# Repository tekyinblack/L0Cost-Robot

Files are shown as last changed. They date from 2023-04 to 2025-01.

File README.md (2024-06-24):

# L0Cost-Robot
This repository holds code for the L0Cost robot project which aims to create designs for robots which don't exceed $20. Inevitably this limit will get broken, but the limit will only increase with general inflation, not wild spending budgets!
The current target platform is the ESP32-CAM board as it provides a good mix of faclities without needing modification. The aim is not to make this platform totally autonomous, but to place control elsewhere such that, say, it might be controlled from a program on a PC or tablet, and as such be controlled in conjunction with other robots. Some basic video recognition code is included to facilitate basic line following and blob location using the camera.

It is also fully expected that the basic platform wil be augmented with a co-processor to handle more extensive I/O operations

The ESP32-CAM is a powerful microcontroller, with a fitted camera, Wi-Fi, Bluetooth and an SD card reader and while worldwide prices will vary, it does represent very good value for money. 
This module can be used just as a remote video camera with SD card configuration, upgraded to have a pan and tilt mount, then added to a small robot, examples of which will be loaded later. 
One target audience is educators who want an easily configurable and repeatable platform at a low cost to aid in STEM robot deployment.

Example configurations are
Pan & Tilt platform controller from web page
Basic RC robot using TT motors controlled from webpage with video feed
Extended robot with control from PS3, web page or self guided

Further configurations extend the capabilities with a Raspberry Pi Pico 

The file SDcard files.docx details the files on the SD card which are used to configure the robot without having to reload the code to the controller
The file  Command Processing.docx details the current state of the command set used to automate the robot controller.

A structure has not yet been designed to support command input instigation of self guidance features so these may appear in the code as switches but are not yet finalised.

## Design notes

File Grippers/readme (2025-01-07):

These are demonstration programs for grippers using SG90 or MG90 servos
They are to setup the servo to 90 degrees to aid assembly, move the servo between 70 and 120
degrees to test operation, and a program to grip objects, either with feedback from the servo
or from metal contacts in the arms detecting the conductivity of the object being gripped.

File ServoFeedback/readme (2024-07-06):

These are the test and demonstration programs for SG90 or MG90 servos modified to use the feedback signal from the servo
They are:
1. Test the servo panning from 0-180-0 degrees and reading the feedback output. The output is formatted for input to the Arduino serial plotting screen. This also verifies that the servo is working after the modification.
2. Initialise the servo to its current position on start up. Switch off, move the servo arm and switch on so that the operation can be confirmed. Compare this to the way the servo behaves on start up with program 1.
3. Stop the servo being overloaded. With this program running and the servo arm fitted hold the servo arm tight when it tries to turn, the servo should initially attempt to turn but then stop with an error message on the serial console
4. Report the current servo position. The servo will move and a report will be sent to to the serial console where the arm is and when it reaches its destination.

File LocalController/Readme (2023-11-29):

There are two versions of the local controller designed, one using the Arduino Nano format and the other the Raspberry Pi Pico format.
Designs and code for each are held separately in their respective folders

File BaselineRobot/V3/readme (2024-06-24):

This is the code base for the version 3 ESP32 sdk

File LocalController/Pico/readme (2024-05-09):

This is the design and code for the local controller based on a Raspberry Pi Pico associated with the L0Cost robot
The design arose out of a PiWars 2024 entry

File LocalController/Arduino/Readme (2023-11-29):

This folder contains designs and code for the Arduino Nano version of the Local Controller held in their respective folders, as well a pictures of completed boards.

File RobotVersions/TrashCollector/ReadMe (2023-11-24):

Trash Collector
This small robot is equiped with a grab and hopper to collect small pieces of trash and deliver them 
to a dump, using the images viewed through the robots camera.

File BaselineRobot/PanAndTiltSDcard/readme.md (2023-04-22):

This is a typical set of files to run a simple Pan and Tilt system
with two servos and an ESP32-CAM module. 
Customise the files as required to setup the operation and
provide a degree of remote control and automation.
Further details will be on instructables.com tagged as L0cost robot.

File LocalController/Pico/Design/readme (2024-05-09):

Information associated with teh Pico version of the local controller will appear here

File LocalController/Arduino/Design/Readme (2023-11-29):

This folder contains design material for the Arduino version of the Local Controller

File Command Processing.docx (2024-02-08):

# L0Cost Robot Commands

The following tables list the commands the L0Cost robot controller accepts and describes what each command does. This is not a sophisticated command structure and is intended to provide a very simple to implement interface and script facility in order to enable rapid learning and play. The source code is available and while any part of it can be modified, additional commands can be added through blank template functions.

Read this together with the example scripts and web pages to understand what is being done.

Command Source Code | Explanation
0 | An internal command, executed with high priority
1 | A command received from a web browser. An ACK or NACK message is pushed back if the web page can handle it.
2 | A command received as part of a script file. If the command fails, a test flag is set and unset on execution of the next successful command. Until a script command is complete, no further script commands are processed.
3 | A command received from PS3 controller processing. No error indicators are returned
4 | A command received from the serial port. This runs at 115200 baud, and an ACK or NACK message is returned depending on command success. A command may be an ACK, or a NACK from a command sent to a remote machine.

Command Prefix | Explanation
L | This command is for execution on the local machine. The command text is trimmed and forwarded to the local command processor. If the command is not recognised as a local command then an execution failure is returned.
LC | Commands for the local camera operation
LG | Commands for the local video guidance operation
F | This command identifies a script file which is opened and read, the contents being executed. Some commands can only be executed from within script files. If the file fails to open then an execution failure is returned. Script files can contain both local and remote commands but not file commands, script nesting is not yet supported but planned.
X | This command is for execution on a remote machine attached to the serial port. The command text is trimmed and forwarded to the serial port. The serial port is configured to run at 115200 baud.
H | This command passes the string following to the webserver unaltered to be retrieved by a javascript, or other, in the browser. The default string returned is {“type”:null}. For example H{“type”:”user”,”speed”:”20”,”distance”:”9”} might indicate to the browser script that this is user data, the speed value is 20cm/s and the distance is 9cm.
P | This command sends instructions to the PS3 controller, limited to lights status and vibration.
T | This command sets execution flags. TON sets execution flag positive or true, TOFF set the execution flag negative or false, TNULL sets the execution flag to neither.

Guidance Local Commands | Guidance Commands Explanation Guidance commands are ignored when guidance isn’t enabled
VIDEO | Sends frames for streaming when guidance active. This may significantly reduce the frame rate
GUIDE | Activates guidance mode. May change the aspect ratio of any streamed video or interrupt it
GREEN | Sets the individual detection threshold for green pixels on all detection methods. A positive value indicates ‘must be greater’, a negative, ‘must be less’
RED | Sets the individual detection threshold for red pixels on all detection methods. A positive value indicates ‘must be greater’, a negative, ‘must be less’
BLUE | Sets the individual detection threshold for red pixels on all detection methods. A positive value indicates ‘must be greater’, a negative, ‘must be less’
BRIGHT | Applies a fixed brightness ratio to a frame
COLOUR | Sets a value for colour detection
UPDATE | Updates the frame by highlighting detected pixels. Is followed by a value indicating the highlight colour to be used
THRESHOLD | Sets a general threshold value for colour detection
THRESHOLDT | Sets the threshold for the top line in line detection
THRESHOLDC | Sets the threshold for the centre line in line detection
THRESHOLDB | Sets the threshold for the bottom line in line detection
LINE | Run functions for line detection
BLOB | Run functions for blob detection

Camera Local Commands | Camera Commands Explanation Camera commands are disabled when the camera is not active such as when running with PS3 control and guidance turned off. They are prefixed with L
FRAMESIZExx | Camera command to set resolution. xx can be one of the following 10 UXGA(1600x1200) 9 SXGA(1280x1024) 8 XGA(1024x768) 7 SVGA(800x600) 6 VGA(640x480) 5 CIF(400x296) 4 QVGA(320x240) 3 HQVGA(240x176) 0 QQVGA(160x120) Example: LCFRAMESIZE06 sets the camera resolution to VGA
QUALITYxx | Camera command to set the jpeg quality. xx can be from 2 to 63, with 2 being minimum compression/highest quality, 63 being maximum compression/minimum quality. This also impacts the frame rate when viewing video.
BRIGHTxx | Camera brightness setting, xx can be -2, -1, 0, 1 or 2, with 2 being the maximum Example: LCBRIGHT00 sets the cameras brightness value to a medium value.
CONTRASTxx | Camera contrast setting, xx can be -2, -1, 0, 1 or 2, with 2 being the maximum Example: LCCONTRAST-2 sets the cameras contrast setting to minimum
SATxx | Camera colour saturation setting, xx can be -2, -1, 0, 1 or 2, with 2 being the maximum Example: LCSAT02 sets the cameras colour saturation to maximum
EFFECTxx | Camera special effect setting, xx can be one of the following 00 No Effect 01 Negative 02 Grayscale 03 Red Tint 04 Green Tint 05 Blue Tint 06 Sepia Example: LCEFFECT06 sets the camera special effect to a sepia colour tone
AWBx | Camera active white balance is set on when x has a value of 1 and off when x has a value of 0. Example: LCAWB1 turns on active white balance
AWBGAINx | Camera active white balance automatic gain is turned on when x has a value of 1 and off when x has a value of 0. Example: LCAWBGAIN0 turns off the active white balance automatic gain feature.
WBMODExx | Camera automatic white balance modes. xx can be one of the following. 00 Auto 01 Sunny 02 Cloudy 03 Office 04 Home Example: LCWBMODE01 sets the automatic white balance mode to compensate for a sunny day
AECx | Camera automatic exposure correction is turned on when x has a value of 1 and off when x has a value of 0. Example: LCAEC1 turns on the feature
AECDSP0 | Camera automatic exposure digital signal processing is turned on when x has a value of 1 and off when x has a value of 0. Example: LCAECDSP1 turns on the feature
AELEVELxx | Camera automatic exposure level, xx can be set to -2, -1,0,1 or 2 Example:LCAELEVEL-2 set automatic exposure to lowest level
AGCx | Camera automatic gain control is turned on when the value of x is 1 and off when the value of x is 0. Example: LCAGC1 turns on Automatic gain control
AGCGAINx | Camera automatic gain control ceiling, where x can be from 0 to 6, and the gain ceiling increases as a power of two from 1, 2, 4, 8, 16, 32 Example: LCAGCGAIN3 set the automatic gain ceiling to 8 times
BPCx | Camera black pixel correction feature is turned on when the value of x is 1 and off when the value of x is 0 Example: LCBPC1 turns on the black pixel correction feature
WPCx | Camera white pixel correction feature is turned on when the value of x is 1 and off when the value of x is 0 Example: LCWPC0 turns off the white pixel correction feature
RAWGMAx | Camera gamma correction feature is turned on when the value of x is 1 and off when the value of x is 0 Example: LCRAWGMA1 turns on the gamma correction feature
HMIRRORx | Camera horizontal mirror feature is activated when the value of x is 1 and deactivated when the value of x is 0. Example: LCHMIRROR1 reverses the camera image horizontally
FLIPx | Camera vertical flip feature is activated when the value of x is 1 and deactivated when the value of x is 0. Example: LCFLIP1 inverts the camera image vertically
DCWx | Camera digital scaling feature is activated when the value of x is 1 and deactivated when the value of x is 0. Example: LCDCW0 turns of the digital scaling feature

Local Commands | General commands
FLASHON | Independently of the camera, turns on the camera illumination led
FLASHOFF | Independently of the camera, turns off the camera illumination led
FLASHPEEK | Independently of the camera, turns on the camera illumination led for 5 seconds
TOGGLEFLASH | Independently of the camera, turns on the camera illumination led if it’s off, and turns it off if it’s on.
MTRATTACH | Attaches the motor pins for local command control
MTRDETACH | Detaches the motor pins allowing independent control
MTRTIMEOUTxxxx | Detaches the motor pins after the timeout period xxxx in milliseconds
RESET | Reboot the L0cost robot controller
PICO | Routes serial input commands to alternate command processor for PiWars
PICOOFF | Turns off Pico processing
DEBUGON | Turn debug output on
DEBUGOFF | Turn debug output off

Local Commands | Script commands
REPEAT | Closes the current script file and reopens it for execution from the beginning
PAUSExxxx | Pauses script processing for xxxx milliseconds
SKIPyxxx | Skips the following xxx script file lines depending on the status of the execution status. If y is F, then skip is executed if execution status is failure, else, if y is S then skip is executed if execution status is success. If y is U then skip executed unconditionally. xxx can be negative.

Local Commands | Servo commands xx can be either pin 12 or 13 for servos
SxxAzzzz | Positions servo on pin xx to position zzzz Example: LS12A0045 moves servo on pin 12 to 45 degrees. If the range of the servo angle is exceeded then the new position is the limit exceeded.
SxxIzzzz | Positions servo on pin xx to a position zzzz relative to the current servo position Example: LS13I-025 moves the servo on pin 13 to a position 25 degrees less than the current position. If the set default range of the servo angle is exceeded then the new position is the limit exceeded.

SxxDyzzzzaaaa

Sets defaults for the servo attached to pin xx.

When y is M, zzzz represents the default centre position, it defaults to 90. The value aaaa is ignored. The command will fail if the value exceeds the default min and max servo positions set.

Example: S13DM0086 set the default central position for the servo on pin 13 to 86 degrees.

When y is X, zzzz represent the default maximum servo angle and aaaa represents the default minimum servo angle, which must be equal to or greater than zero. They default to 0 and 180 respectively. The command will fail if the new values make any current servo values invalid.

Example: LS12DX02700090 sets the default maximum angle for the servo on pin 12 to 270 degrees and the minimum angle to 90.

When y is T, zzzz represent the signal timing for zero degrees rotation and aaaa represents signal timing for maximum rotation.
SxxC | Positions the servo on pin xx to the default central position Example: S12C positions the servo on pin 12 to its default central position
SxxN | Positions the servo on pin xx to the default minimum position Example: S12N positions the servo on pin 12 to its default minimum position
SxxM | Positions the servo on pin xx to the default maximum position Example: S12M positions the servo on pin 12 to its default maximum position

Local Commands | Motor commands
STOP | Stops all motors immediately
HALT | Stops all motors smoothly
| General motor command
MTRxxxxyyyyzzzz | Activates the motors with left at power level xxxx and right at level yyyy for the runtime of zzzz milliseconds
| PS3 controller – standard steering
MTRppppqqqqrrrrssss | Activates the motors with qqqq taken as F/R power and rrrr taken as L/R direction
| PS3 controller – tank steering
MTRppppqqqqrrrrssss | Activates the motors with left at power level qqqq and right at power level ssss. Negative power is taken as reverse.

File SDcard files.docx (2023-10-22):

SDcard files

There are three file types expected on the SDcard, configuration files, read once when the L0cost controller boots, html files and script files, read either when the controller boots, in the case of the startup script, immediately when the controller initialisation is complete, in the case of the main script, or when requested in a command input.

The configuration files are config.txt (the name is fixed), the wifi configuration file, which is listed in the config file and the PS3 configuration file, also listed in the config file. Because the L0cost controller can only run either Bluetooth or wifi separately and not concurrently, only one for these two file can be in the config file.

Configuration file.

The config file has a fixed format and the lines must be in the order listed, though lines at the end will use default values if not included.

Line | Parameter | Explanation
1 | Mode | Sets the mode of operation. This value is interpreted and sets the execution flags in the controller to cause the controller to behave in the desired manner.
2 | Hostname | This is the name the robot will be known by when requested, typically in response to a command or for wireless network identification. It should be a valid network name of not more than 20 characters or it will be truncated.
| | Wifi config and PS3 configs are mutually exclusive
3 | Wifi config | This is the name of the file on the SDcard containing the wifi configuration information. Example: wifi.txt would expect the wifi configuration details to be contained in the file called wifi.txt on the SDcard. This name is actually the default.
| PS3 config | This is the name of the file on the SDcard containing the PS3 configuration information. Example: PS3.txt would expect the PS3 configuration details to be contained in the file called PS3.txt on the SDcard. This name is actually the default.
4 | Startup script | This is the name of the file containing the startup script. This script will accept changes to the controller configuration to customise the usage, such as setup camera framesize or servo defaults. This entry must be here, even if pointing to an empty file, if a main script is required.
5 | Main script | This is the name of the file containing the Main script which will be executed as soon as the setup for the controller is complete.

Table of Modes of Operation

Config Mode Entry
| In all BASIC modes, pins 12 and 13 are used to provide drive signals to transistors switching current to motors. Remote commands are passed to the serial port without handshaking
BASICSTA | Runs as a wifi client with a web page and negative drive pin control
BASICAP | Runs as a wifi access point with a web page and negative drive pin control
BASICPS3 | Runs with PS3 controller input and negative drive pin control
BASICSTA+ | Runs as a wifi client with a web page and positive drive pin control
BASICAP+ | Runs as a wifi access point with a web page and positive drive pin control
BASICPS3+ | Runs with PS3 controller input and positive drive pin control
| REMOTE modes use pins 12 and 13 for handshaking on the serial communications
REMOTESTA | Runs as wifi client with a web page
REMOTEAP | Runs as wifi access point with a web page
REMOTEPS3 | Runs with PS3 controller input
| SERVO modes assign pins 12 and 13 to be used for controlling servos. Remote commands are passed to the serial port without handshaking
SERVOSTA | Runs as a wifi client with a webpage
SERVOAP | Runs as a wifi access point with a webpage
SERVOPS3 | Runs with PS3 controller input
| SOKOBAN modes assign motor control to pins 3, 12 and 13 to drive logic gates and a motor controller to provide forward/reverse/turn control from 3 pins. Remote commands are passed to the serial port without handshaking, serial command input is disabled.
SOKOBANSTA | Run as a wifi client with a web page.
SOKOBANAP | Run as a wifi access point with a web page
SOKOBANPS3 | Run with PS3 controller input

Wifi configuration

The wifi file has a fixed format and the lines must be in the order listed, though lines at the end will use default values if not included.

Line | Parameter | Explanation
1 | SSID | This is the SSID that as a client the controller will attempt to connect to, or as an access point, will broadcast.
2 | password | This is the password associated with the SSID
3 | Html file | This is the name of the html file on the SDcard which will be used as the home web page for the controller. The default page serves the video stream from the camera.
4 | Webserver port | This is the port on the controller webserver used to serve the default home web page. Defaults to 80
5 | Streaming port | This is the port on the controller webserver used to serve the video stream. Defaults to 81.

PS3 Configuration

The PS3 file has a fixed format and the lines must be in the order listed, though lines at the end will use default values if not included. The purpose of the file is to firstly connect the PS3 controller over Bluetooth to the L0cost controller. The rest of the file maps the input from the PS3 controller to commands that can either be executed by the L0cost controller or routed to the remote controller. There are many entries and each can either be active or not. Entries not included at the end of the list are deemed to be not active, but all entries beforehand must be in the fixed sequence listed in the table below. On startup, this file is read and each entry loaded into a translation table, which when a PS3 control is activated, is converted into a command prefix followed by any values received from the controller. Lines beginning with a 0 are ignored and the maximum command prefix length is 19 characters

Line | Example Prefix | Explanation
1 | A0:5A:5A:A0:09:84 | MAC address of the PS3 controller to be paired
2 | LMTR | left and right joystick values are appended Example: LMTR0000025500000255
3 | XMTR | left and right joystick values are appended Example: XMTR0000025500000255
4 | XLJP | left joystick pressed, the command has no values
5 | XLJR | left joystick released, the command has no values
6 | XRJP | right joystick pressed, the command has no values
7 | XRJR | right joystick released, the command has no values
8 | XUPV | up button values, the button pressure value is appended Example: XUPV0255
9 | XUBP | up button pressed, the command has no values
10 | XUBR | up button released, the command has no values
11 | XRBV | right button values, the button pressure value is appended Example: XRBV0255
12 | XRBP | right button pressed, the command has no values
13 | XRBR | right button released, the command has no values
14 | XDBV | down button values, the button pressure value is appended Example: XDBV0255
15 | XDBP | down button pressed, the command has no values
16 | XDBR | down button released, the command has no values
17 | XLBV | left button values, the button pressure value is appended Example: XLBV0255
18 | XLBP | left button pressed, the command has no values
19 | XLBR | left button released, the command has no values
20 | XXBV | cross button values, the button pressure value is appended Example: XXBV0255
21 | XXBP | cross button pressed, the command has no values
22 | XXBR | cross button released, the command has no values
23 | XSBV | square button values, the button pressure value is appended Example: XSBV0255
24 | SBP | square button pressed, the command has no values
25 | XSBR | square button released, the command has no values
26 | XTBV | triangle button values, the button pressure value is appended Example: XTBV0255
27 | XTBP | triangle button pressed, the command has no values
28 | XTBR | triangle button released, the command has no values
29 | XCBV | circle button values, the button pressure value is appended Example: XCBV0255
30 | XCBP | circle button pressed, the command has no values
31 | XCBR | circle button released, the command has no values
32 | XLSV | left shoulder values, the button pressure value is appended Example: XLSV0255
33 | XLSP | left shoulder pressed, the command has no values
34 | XLSR | left shoulder released, the command has no values
35 | XRSV | right shoulder values, the button pressure value is appended Example: XRSV0255
36 | XRSP | right shoulder pressed, the command has no values
37 | XRSR | right shoulder released, the command has no values
38 | XLTV | left trigger values, the button pressure value is appended Example: XLTV0255
39 | XLTP | left trigger pressed, the command has no values
40 | XLTR | left trigger released, the command has no values
41 | XRTV | right trigger values, the button pressure value is appended Example: XRTV0255
42 | XRTP | right trigger pressed, the command has no values
43 | XRTR | right trigger released, the command has no values
44 | XSLP | select button pressed, the command has no values
45 | XSLR | select button released, the command has no values
46 | XSTP | start button pressed, the command has no values
47 | XSTR | start button released, the command has no values
48 | XPSP | PS3 button pressed, the command has no values
49 | XPSR | PS3 button released, the command has no values

HTML file

The wifi config may contain a web page file name to be used to load into the webserver as the default home page. If the load of this file fails then a default page is loaded which displays the video stream from the server. The webserver only serves this page and any other items that are required on the page must be obtained from another server.

The option to dynamically update this page may be added at a later date.

Startup script file

This file is read as part of the setup phase of the L0cost robot controller software and is intended to initialise various parameters for the camera or attached servos and motors. Remote commands encountered are executed but file commands are not. Local commands may not be executed.

Main script file

This file is read at the start of normal processing and may contain any valid script commands. This script may be the only thing the robot does, excluding all other command input.

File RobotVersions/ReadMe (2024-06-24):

These are the different versions of robots designed using the L0Cost Robot Controller and TinkerCAD

Sokoban Bot
This small robot is intended to play a physical version of the compouter game, Sokoban,
in which the player has to move crates around in an imaginary warehouse, the objective to sovle
the problem of moving the crates to the required positions by only pushing them. This robot can also be 
used for line and target following. 

Trash Collector
This small robot is equiped with a grab and hopper to collect small pieces of trash and deliver them 
to a dump, using the images viewed through the robots camera.

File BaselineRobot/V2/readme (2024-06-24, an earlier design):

This repository is the end of the code using the version 2 of the ESP32 sdk
Future versions use version 3 which includes changes to the PWM routines

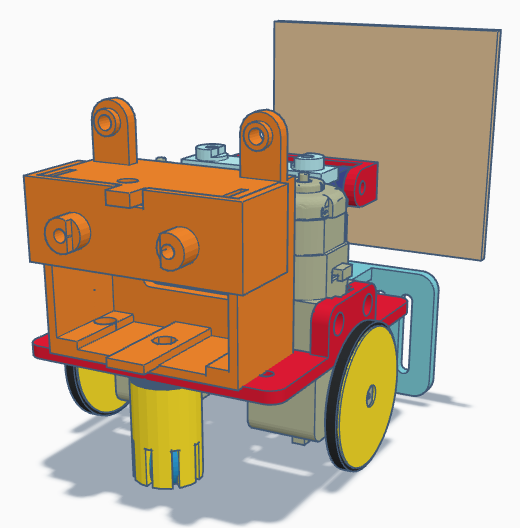
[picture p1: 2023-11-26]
RobotVersions/Sokoban/Pictures/pic3.png

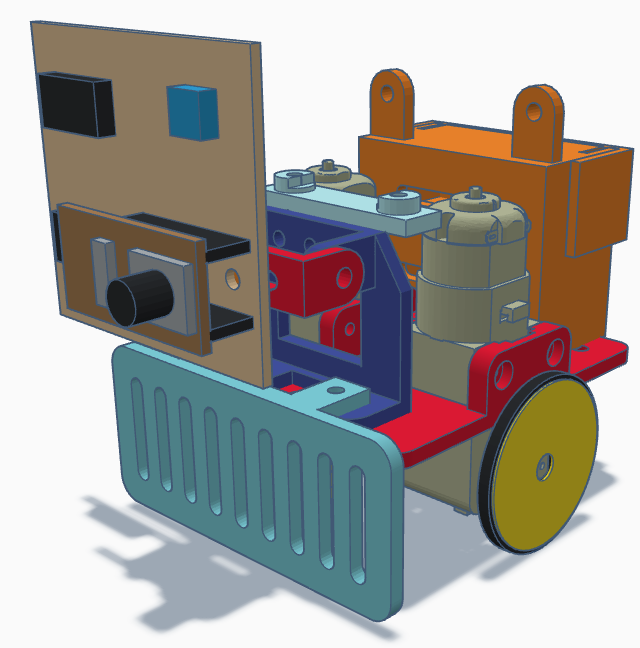
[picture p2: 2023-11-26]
RobotVersions/Sokoban/Pictures/pic1.png

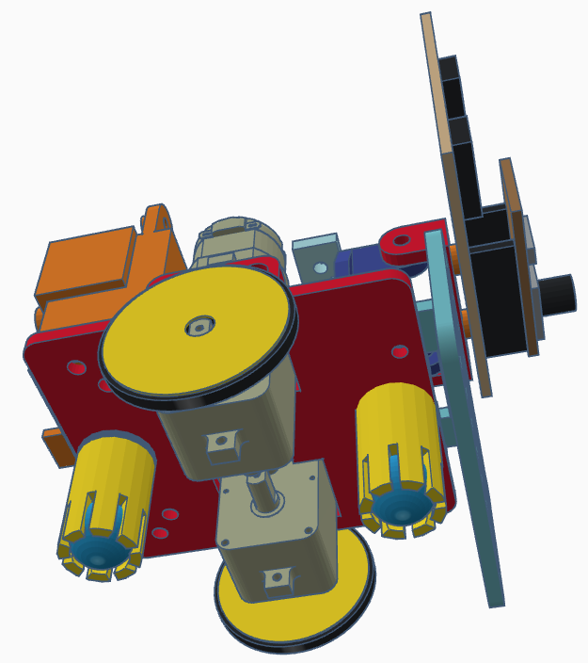
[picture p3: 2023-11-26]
RobotVersions/Sokoban/Pictures/pic2.png

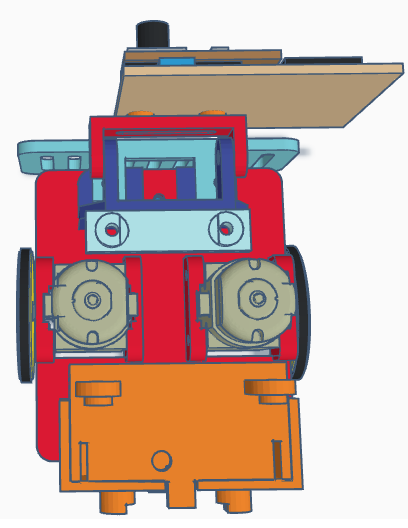
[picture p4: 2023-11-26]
RobotVersions/Sokoban/Pictures/pic4.png

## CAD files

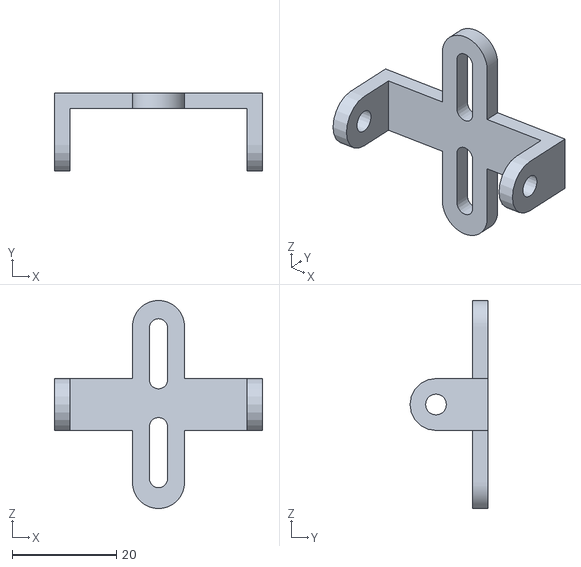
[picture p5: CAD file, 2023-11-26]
RobotVersions/Sokoban/3Dprinterfiles/Sokoban Robot Vertical Camera Mount.stl
40.0 x 15.0 x 40.0

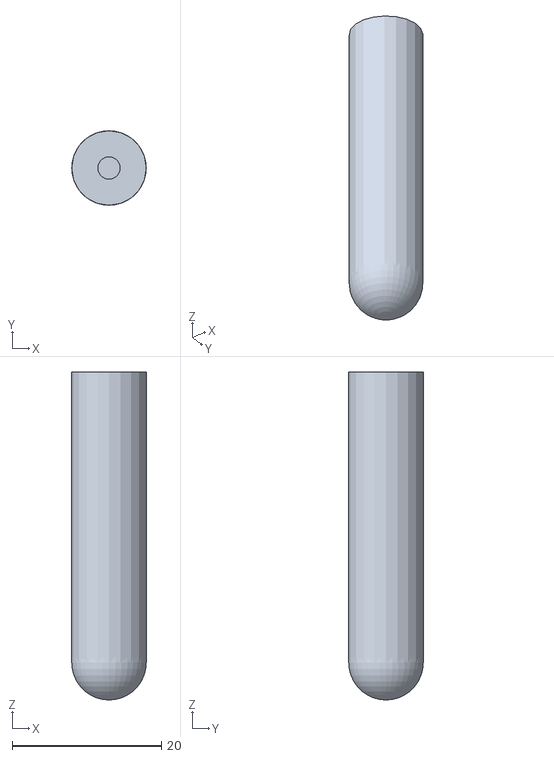
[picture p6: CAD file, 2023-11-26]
RobotVersions/Sokoban/3Dprinterfiles/Sokoban Robot Fixed Skid 68mm.stl
10.0 x 10.0 x 44.0

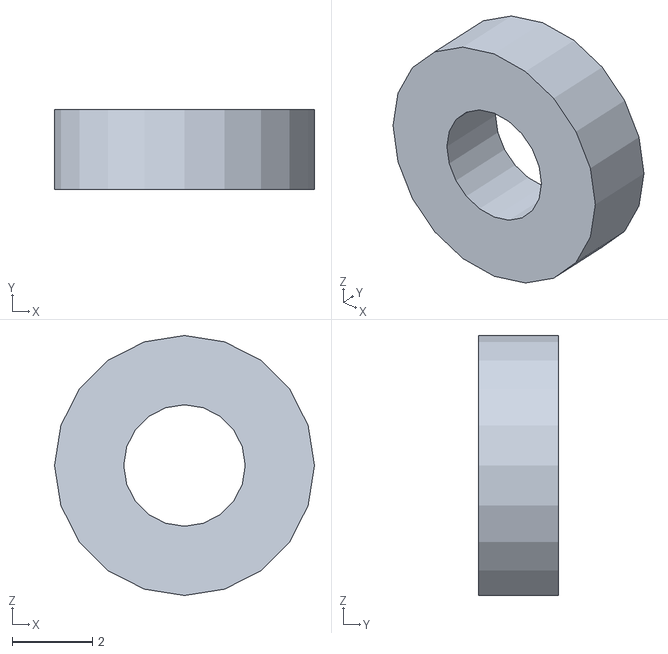
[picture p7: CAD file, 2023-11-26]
RobotVersions/Sokoban/3Dprinterfiles/Shim.stl
6.50 x 2.00 x 6.50

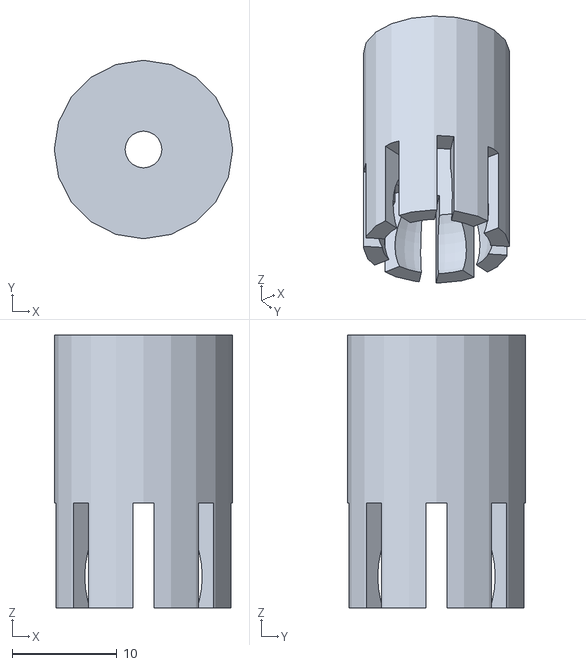
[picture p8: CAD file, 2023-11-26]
RobotVersions/Sokoban/3Dprinterfiles/Sokoban Robot Ball Bearing Skid.stl
17.0 x 17.0 x 26.0

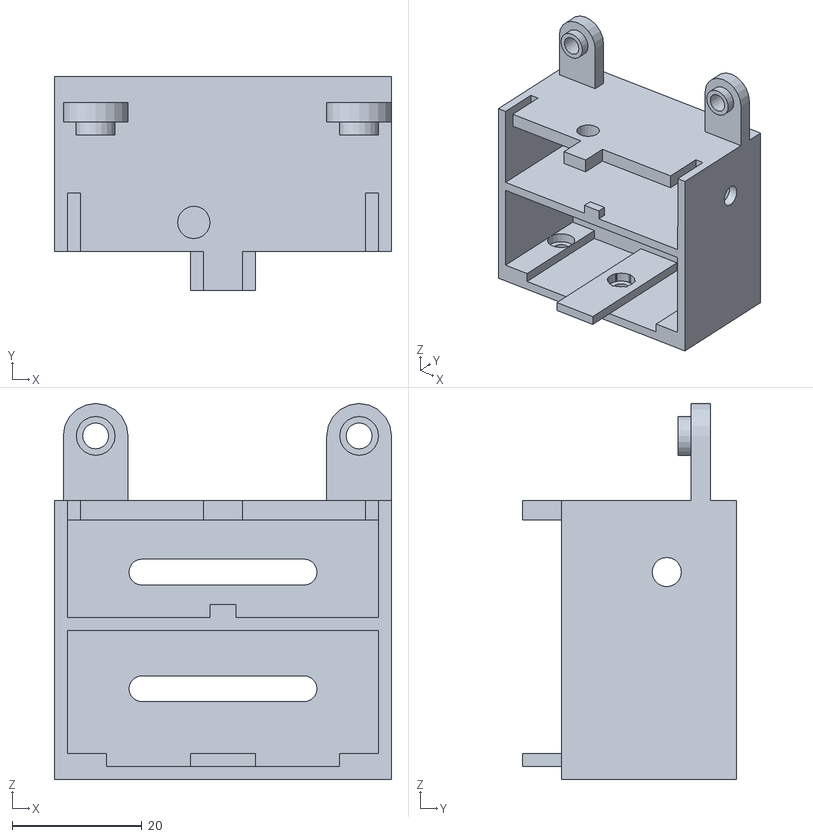
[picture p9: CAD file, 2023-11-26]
RobotVersions/Sokoban/3Dprinterfiles/Sokoban Robot LiPo Battery Box.stl
52.0 x 33.0 x 58.0

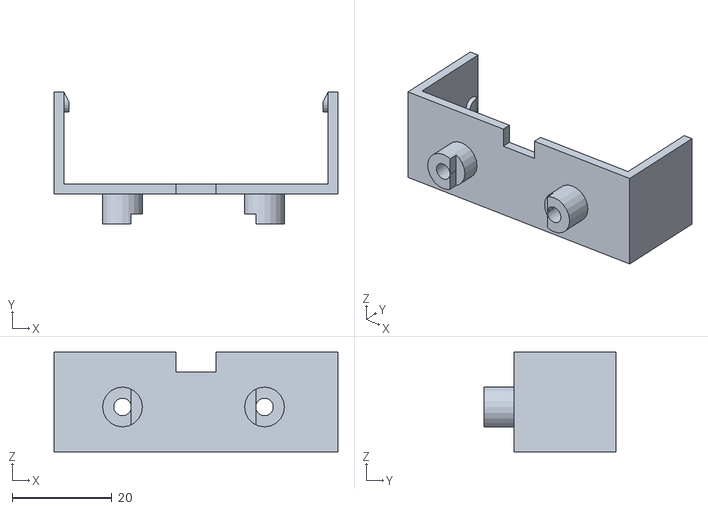
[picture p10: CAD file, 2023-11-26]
RobotVersions/Sokoban/3Dprinterfiles/Sokoban Robot LiPo Voltmeter.stl
57.0 x 26.5 x 20.0

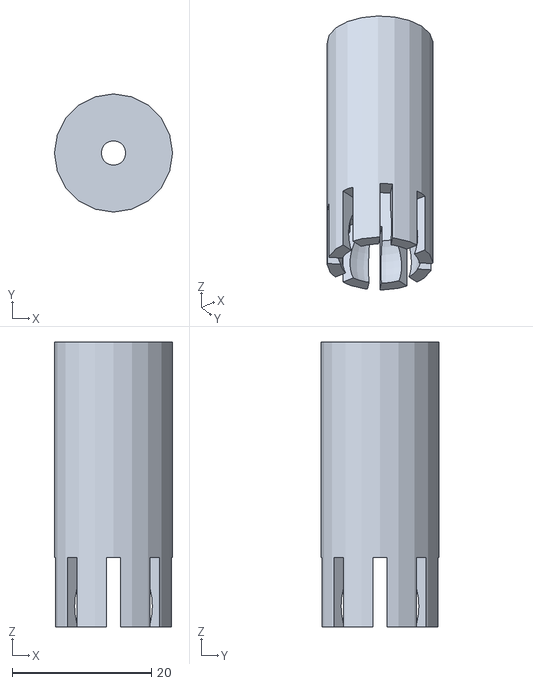
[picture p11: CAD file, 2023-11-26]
RobotVersions/Sokoban/3Dprinterfiles/Sokoban Robot Ball Bearing Skid 68mm.stl
17.0 x 17.0 x 41.0

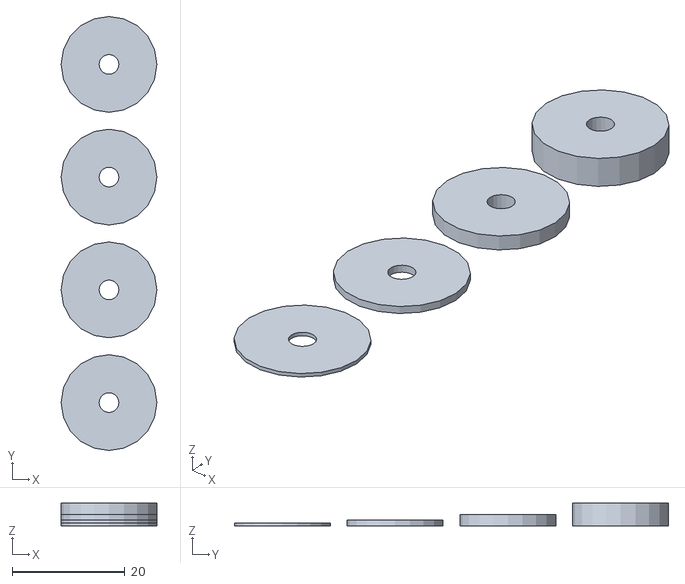
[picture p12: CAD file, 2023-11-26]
RobotVersions/Sokoban/3Dprinterfiles/Sokoban Robot Skid Spacers.stl
17.0 x 77.0 x 4.00

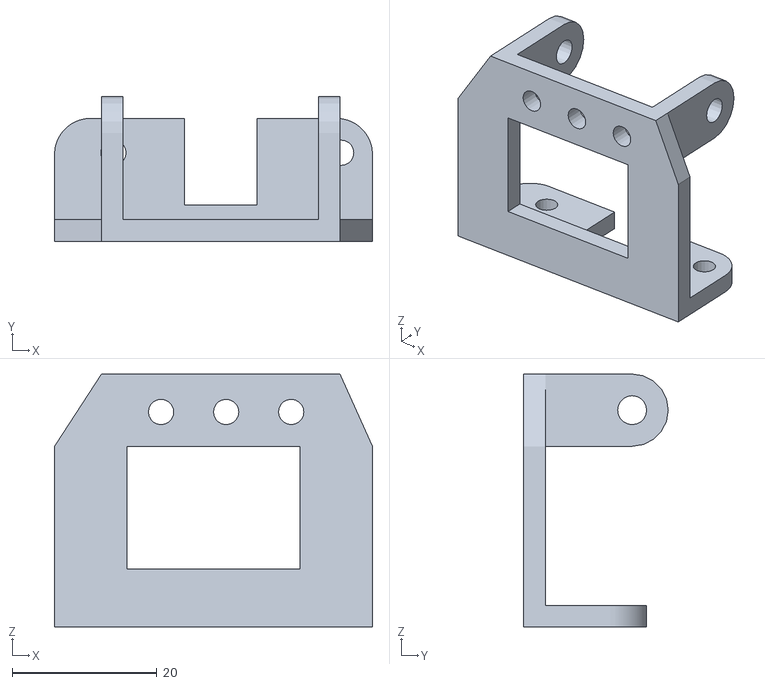
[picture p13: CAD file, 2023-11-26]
RobotVersions/Sokoban/3Dprinterfiles/Sokoban Robot Camera Stand.stl
44.0 x 20.0 x 35.0

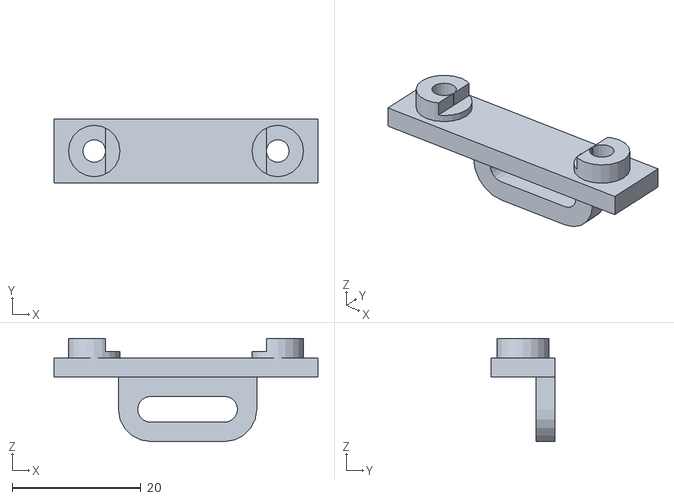
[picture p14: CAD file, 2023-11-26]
RobotVersions/Sokoban/3Dprinterfiles/Sokoban Robot NiCad Voltmeter.stl
41.0 x 10.0 x 16.0

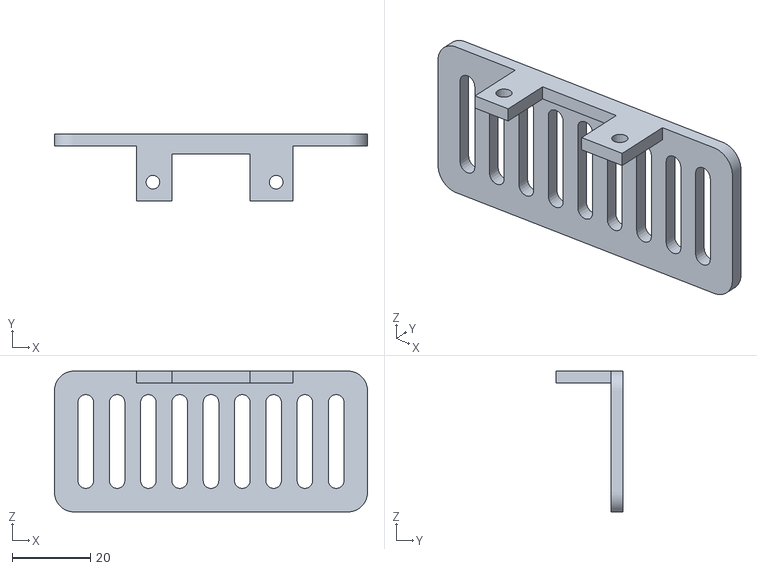
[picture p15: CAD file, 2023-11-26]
RobotVersions/Sokoban/3Dprinterfiles/Sokoban Robot Buffer.stl
80.0 x 17.0 x 36.0

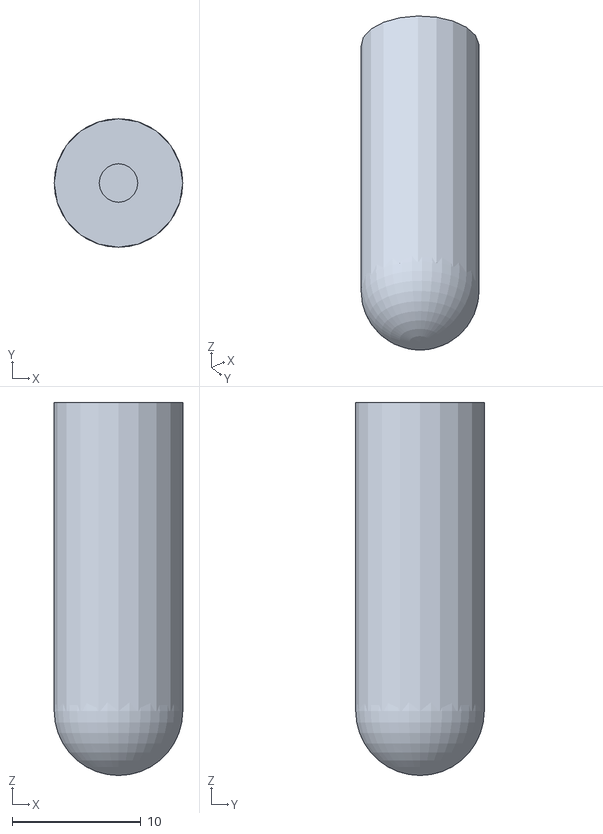
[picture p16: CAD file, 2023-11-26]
RobotVersions/Sokoban/3Dprinterfiles/Sokoban Robot Fixed Skid.stl
10.0 x 10.0 x 29.0

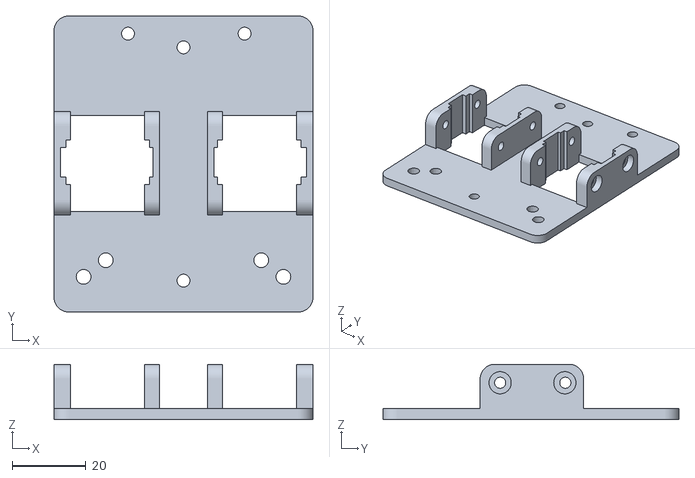
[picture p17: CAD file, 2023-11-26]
RobotVersions/Sokoban/3Dprinterfiles/Sokoban Chassis.stl
70.0 x 80.0 x 15.0

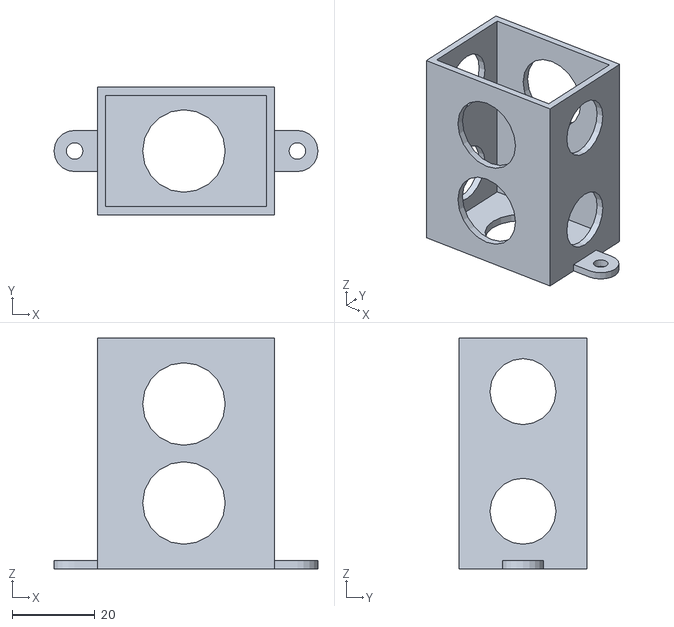
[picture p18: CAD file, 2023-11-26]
RobotVersions/Sokoban/3Dprinterfiles/Sokoban Robot NiCad Battery Box.stl
64.0 x 31.0 x 56.0

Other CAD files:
RobotVersions/Sokoban/3Dprinterfiles/Sokoban Robot Camera Mount Spacer.stl
RobotVersions/Sokoban/3Dprinterfiles/Sokoban Robot Horizontal Camera Mount.stl

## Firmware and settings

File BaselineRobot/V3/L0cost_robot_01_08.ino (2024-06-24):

/*
Version 01_08 is a checkpoint version following Piwars 2024
All piwars specic code will be removed or incorporated into the main +
Feature development has been frozen to concentrate on demonstrations, optimisation and readability
*/
/* With debug set on, no local pin assignments and serial is assumed to be used for debug output only
All other functions continue to work
*/
/*  In the BASIC modes, pins 12 and 13 are used to provide drive signals to transistors switching current to motors
    The standard mode is to drive PNP transistors
  - if in BASICSTA mode, serial passthru on, no handshake, Wifi client, web page input, local drive commands processed to drive pins
  - if in BASICAP mode, serial passthru on, no handshake, Wifi Access Point, web page input, local drive commands processed to drive pins
  - if in BASICPS3 mode, serial passthru on, no handshake, PS3 input, local drive commands processed to drive pins
    The plus modes are to drive NPN transistors
  - if in BASICSTA+ mode, serial passthru on, no handshake, Wifi client, web page input, local drive commands processed to drive pins as positive
  - if in BASICAP+ mode, serial passthru on, no handshake, Wifi Access Point, web page input, local drive commands processed to drive pins as positive
  - if in BASICPS3+ mode, serial passthru on, no handshake, PS3 input, local drive commands processed to drive pins as positive

  - For SOKOBAN modes, drive pins are 3 and 12 (normally have reserved roles) and 13 is PWM output. This is a specialised robot role with minimal configuration
  - if in SOKOBANSTA mode, serial passthru off, no handshake, Wifi client, web page input, alternative drive pins, L293D decode
  - if in SOKOBANAP mode, serial passthru off, no handshake, Wifi Access Point, web page input, alternative drive pins, L293D decode
  - if in SOKOBANPS3 mode, serial passthru off, no handshake, PS3 input, alternative drive pins, L293D decode

  - if in REMOTESTA mode, serial passthru on, handshake on, Wifi client, web page input
  - if in REMOTEAP mode, serial passthru on, handshake on, Wifi Access Point, web page input
  - if in REMOTEPS3 mode, serial passthru on, handshake on, PS3 controller input
  
  - The SERVO modes make it easy to add a Pan and Tilt function to some of the other L0Cost robot builds
  - if in SERVOSTA mode, serial passthru on, no handshake, Wifi client, web page input, servo commands processed to pins 12 and 13
  - if in SERVOAP mode, serial passthru on, no handshake, Wifi Access Point, web page input, servo commands processed pins 12 and 13
  - if in SERVOPS3 mode, serial passthru on, no handshake, PS3 controller input, servo commands processed pins 12 and 13
  */
/*
Required libraries
PS3 Controller Host by Jeffrey van Pernis
ESP32Servo by Kevin Harrington, John K Bennett
*/
#include "esp_camera.h"
#include "ESPmDNS.h"
#include <WiFi.h>
#include "esp_timer.h"
#include "img_converters.h"
#include "Arduino.h"
#include "fb_gfx.h"
#include "soc/soc.h"           // disable brownout problems
#include "soc/rtc_cntl_reg.h"  // disable brownout problems
#include "esp_http_server.h"
#include "FS.h"
#include "SD_MMC.h"
#include "SPI.h"
#include <Ps3Controller.h>
#include <ESP32Servo.h>


// ===================
// Select camera model
// ===================
//#define CAMERA_MODEL_WROVER_KIT // Has PSRAM
//#define CAMERA_MODEL_ESP_EYE // Has PSRAM
//#define CAMERA_MODEL_ESP32S3_EYE // Has PSRAM
//#define CAMERA_MODEL_M5STACK_PSRAM // Has PSRAM
//#define CAMERA_MODEL_M5STACK_V2_PSRAM // M5Camera version B Has PSRAM
//#define CAMERA_MODEL_M5STACK_WIDE // Has PSRAM
#define CAMERA_MODEL_AI_THINKER  // Has PSRAM

#include "camera_pins.h"
//<<<<<<<<<<<<<<<<<<<<<<<<<<<<<<<<<<<<<>>>>>>>>>>>>>>>>>>>>>>>>>>>>>>>>>>>>
// the following include contains the main function and variable declarations
#include "L0cost_robot_dcl.h"
long lastconv = 0;

// the main startup routine
void setup() {
  WRITE_PERI_REG(RTC_CNTL_BROWN_OUT_REG, 0);  //disable brownout detector


  // Turn off flash
  pinMode(FLASH_PIN, OUTPUT);
  digitalWrite(FLASH_PIN, LOW);
  flashState = 0;

  // setup flash LED control
  // ledcSetup(flashPWMChannel, PWMFreq, PWMResolution);
  // ledcAttachPin(FLASH_PIN, flashPWMChannel);
  //   ledcSetup(flashPWMChannel, PWMFreq, PWMResolution);
  ledcAttach(FLASH_PIN, PWMFreq, PWMResolution);
  ledcWrite(flashPWMChannel, 0);

  // initialise builtin led for status indicator
  pinMode(LED_BUILTIN, OUTPUT);
  digitalWrite(LED_BUILTIN, LOW);

  // Start serial comms

  if (debugSerial || execSerial) { Serial.begin(115200); }
  if (debugSerial) { Serial.setDebugOutput(false); }

   // indicate processing has started
  if (debugSerial) { Serial.println("Starting...."); }
  if (debugSerial) { Serial.printf("%s %s %s",__FILE__,__DATE__,__TIME__); }

  if (debugSerial) {Serial.println(getCpuFrequencyMhz());}

  // Writing a high output on pins 12 and 13 is done to resolve an "error" in 1-bit mode when SD_MMC.begin("/sdcard", true).
  // this may result in brief unpredictable servo or motor behaviour
  pinMode(12, OUTPUT);
  digitalWrite(12, 1);
  pinMode(13, OUTPUT);
  digitalWrite(13, 1);

  // get the sd card data
  // first setup SD card access

  setup_sdcard();

  // read SD card data to get initial configuration, wifi or ps3 data and default webpage if needed

  read_SDcard();

  // reset the pin 12 and 13 fixes
  pinMode(12, INPUT_PULLDOWN);
  pinMode(13, INPUT_PULLDOWN);


  // use camera defines to setup camera access if required
  // if camera is not setup here it is not available later
  if (execVideo || execGuide) {
    camera_config_t config;
    config.ledc_channel = LEDC_CHANNEL_0;
    config.ledc_timer = LEDC_TIMER_0;
    config.pin_d0 = Y2_GPIO_NUM;
    config.pin_d1 = Y3_GPIO_NUM;
    config.pin_d2 = Y4_GPIO_NUM;
    config.pin_d3 = Y5_GPIO_NUM;
    config.pin_d4 = Y6_GPIO_NUM;
    config.pin_d5 = Y7_GPIO_NUM;
    config.pin_d6 = Y8_GPIO_NUM;
    config.pin_d7 = Y9_GPIO_NUM;
    config.pin_xclk = XCLK_GPIO_NUM;
    config.pin_pclk = PCLK_GPIO_NUM;
    config.pin_vsync = VSYNC_GPIO_NUM;
    config.pin_href = HREF_GPIO_NUM;
    config.pin_sscb_sda = SIOD_GPIO_NUM;
    config.pin_sscb_scl = SIOC_GPIO_NUM;
    config.pin_pwdn = PWDN_GPIO_NUM;
    config.pin_reset = RESET_GPIO_NUM;
    config.xclk_freq_hz = 20000000;
    config.frame_size = FRAMESIZE_SVGA;    // default for video streaming
    config.pixel_format = PIXFORMAT_JPEG;  // default for video streaming
    config.grab_mode = CAMERA_GRAB_WHEN_EMPTY;
    if (execGuide) {
      // defaults for video guidance
      config.frame_size = FRAMESIZE_QVGA;  
      config.grab_mode = CAMERA_GRAB_LATEST;
    }

    config.fb_location = CAMERA_FB_IN_PSRAM;
    config.jpeg_quality = 12;
    config.fb_count = 2;

    // Camera init
    execCamera = 1;
    esp_err_t err = esp_camera_init(&config);
    if (err != ESP_OK) {
      if (debugSerial) { Serial.printf("Camera init failed with error 0x%x \n", err); }
      execVideo = 0;
      execGuide = 0;
      execCamera = 0;
      errorTimer = 250;
    }
    if (execGuide) {
      sensor_t *s = esp_camera_sensor_get();
      s->set_framesize(s, (framesize_t)2);      //<<<<<<<<<QVGA?
    }
  }

  // implememt 2 pin motor control
  if (execMotor == 1) {
    if (debugSerial) { Serial.printf("Implementing 2 pin motor control on pins %d and %d \n", rightMotorPin, leftMotorPin); }
    initPWM();
  }

  // implememt 3 pin motor control
  if (execMotor == 2) {
    if (debugSerial) { Serial.printf("Implementing 3 pin motor control with L293D on pins %d and %d \n", rightMotorPin, leftMotorPin, enableMotorPin); }
    initThreePin();
  }

  // initialise servos
  if (execServo == 1 and execMotor == 0) {
    // initialise pan/tilt servo mode
    // init servo12 and servo13
    initServos();
  }

    // read and process startup script file
  if (execScript) {
    scriptStatus = 1;
    strcpy(scriptFile, configStartup);
    while (scriptStatus) {
      fileProcessor(0);
    }
  }

  // if WiFi selected by option, process connection
  if (execWiFi) {
    // Wi-Fi connection
    //  WiFi.config(local_IP,gateway,subnet,primaryDNS,secondaryDNS);
    WiFi.setHostname(configHostname);
    // if not APT then setup a wifi client
    if (execWiFi == 1) {
      WiFi.begin(ssid, password);
      while (WiFi.status() != WL_CONNECTED) {
        delay(500);
        if (debugSerial) { Serial.print("."); }
      }
      if (debugSerial) { Serial.println(""); }
      Serial.println("WiFi connected");
    } else {  // otherwise create a wifi hot spot access point
      if (debugSerial) { Serial.println("Configuring access point..."); }
      WiFi.softAP(ssid, password);
      IPAddress myIP = WiFi.softAPIP();
      if (debugSerial) {
        Serial.print("AP IP address: ");
        Serial.println(myIP);
      }
    }

    // Start streaming web server
    startWebServer();

    if (debugSerial) {
      Serial.print("Web Server Ready! Go to: http://");
      Serial.println(WiFi.localIP());
    }

    // register the hostname for use with DNS
    if (!MDNS.begin(configHostname)) {
      if (debugSerial) { Serial.println("Error starting mDNS"); }
    }
  } else if (debugSerial) {
    Serial.println("WiFi and Web page services not selected");
  }

  // PS3 setup routines
  if (execPS3) {
    Ps3.attach(notify);
    Ps3.attachOnConnect(onConnect);
    Ps3.begin(configPS3);
    if (debugSerial) { Serial.println("PS3 services initialised"); }
  }


  // Setup for processing main script file in main Loop
  if (execScript) {
    scriptStatus = 1;
    strcpy(scriptFile, configMain);
  }



  //************ end of setup
}

/*******************************************************************************************
the loop function runs several recurring routines
   error indicator via flashing inbuilt LED
   switches off timed FLASH illumination
   checks for serial input
   sequences script file processing
   switches off timed motor run 
   schedules camera calibration
   schedules video guidance
   schedule demonstration routines
schedules the reading of command files */
void loop() {
  int status = 0; // general return status variable


  // timing vaiables to measure video guidance routines effectiveness
  long startconv = 0;
  long endconv = 0;
  long enddetect = 0;
  long endoverlay = 0;
  long endloop = 0;
  long convgap = 0;

  loopTimer = millis();  // all functions on each iteration of the loop use this value

  //*********************************************************************************

  // display Wifi is active via flashing LED
  if (execWiFi) {
    // wifi indicator LED
    if (WiFi.status() == WL_CONNECTED) {
      if (ledTimer <= loopTimer) {
        ledTimer = loopTimer + errorTimer * 2;
        digitalWrite(LED_BUILTIN, HIGH);
      }
      if (ledTimer - errorTimer <= loopTimer) {
        digitalWrite(LED_BUILTIN, LOW);
      }
    } else {
      digitalWrite(LED_BUILTIN, LOW);
    }
  }
  //*********************************************************************************
  // switch off flash led if time expired
  if (flashTimer < loopTimer) {
    cmdProcessor("LFLASHOFF", 0);
    flashTimer = FLASH_ON_TIME;
  }
  //*********************************************************************************
  // check for and process serial input
  // this is run continuously until serial processing is complete or an exception occurs
  // out of input data, excessive input data and function not active are exceptions
  while (!serialProcessor(0)) {};

  //*********************************************************************************
  // process script file if active
  fileProcessor(1);

  // take script out of pause if timer expired
  if (scriptProcess == 3) {
    //if scriptTimer has expired, set script to process next command
    if (scriptTimer <= loopTimer) {
      if (debugSerial) { Serial.println("Script pause ended"); }
      scriptProcess = 2;
    }
  }

  //*********************************************************************************
  // check if motor command has expired
  // if so, stop robot
  if (execMotor && execPWM) {
    if (motorTimer <= loopTimer) {
      if (execMotor == 1) {
        ledcWrite(rightMotorPWMSpeedChannel, 0);
        ledcWrite(leftMotorPWMSpeedChannel, 0);
      } else if (execMotor == 2) {
        ledcWrite(enableMotorPWMSpeedChannel, 0);
      }
    }
  }

  //*********************************************************************************
  // Video processing routines
  // any incuded print statements are for development testing and will be removed in a later version

  // calibration routine is called in the loop to run a set number of times
  if (execCalibrate) {
    // if timer expired execute calibartion
    if (calTimer < loopTimer) {
      calTimer = calTimer + 500;
      calCount++;
      // check if maximum number of calibration runs
      if (calCount > calMax || calibrate(calType, calColour)) {
        execCalibrate = 0;
      }
    }
  }

    //*********************************************************************************
  // if video guidance is in use and blobUpdate or lineUpdate has been requested
  // if viewing on a webpage this should be set automatically, otherwise set by command
  if (execGuide && (blobUpdate || lineUpdate)) {
    // only execute this section if automatic video guidance in use
    if (!frameAvailable) {
      //     Serial.printf("Start conv: %d \n", millis());
      // get frame into working frame buffer
      startconv = millis();
      convgap = lastconv - startconv;
      lastconv = startconv;
      videoProcessing();
      endconv = millis();
      //    Serial.printf("End conv: %d \n", millis());
    }

    // if frame available, process selected detection routines
    if (frameAvailable == 1) {
      // call line detection processing. 
      // three frame positions are provided here, top, centre and bottom, and three 'lines' can detected and reported on in each
      // the position of top, centre and bottom can be defined in commands to suit the camera
      // by default, only the centre position is updated, selecting BOTTOM updates both centre and bottom, and selecting
      // TOP updates top, centre and bottom

      if (execMask) {
        writeMask(maskColour);
      }
      if (execLine) {
        switch (execLineProcessing) {
          case 1:
            status = findLineTop(colourDetect);
          case 2:
            status = findLineBottom(colourDetect);
          default:
            status = findLineCentre(colourDetect);
        }
        if (execDemo) {
          //execute line following commands
        }
      }
      // call blob detection processing
      // the initial reporting is targeted on the centre of the largest blob detected
      else if (execBlob) {
        long videoTime = millis();
        switch (execBlobProcessing) {
          case 0:
            // standard blob processing, updates blob location variables
            status = findBlob(colourDetect);
            break;
          case 1:
            // paints a heatmap of colour for video guidance tuning
            heatMap(colourDetect, 1);
            break;
          case 2:
            // paints a colour intensity map  for video guidance tuning
            scanTest(colourDetect);
            break;
          case 3:
            // paints a colour detection map for video guidance tuning
            findColours();
            break;
          default:
            status = findBlob(colourDetect);
            break;
        }
                if (execDemo) {
          //execute target following commands
        }
        // if (debugSerial) { Serial.printf("%d \n", millis() - videoTime); }
      }

      enddetect = millis();

      // end of successful processing, set frame available for processing elsewhere
      // or flag frame processing complete and free frame buffer

      if (execVideo) {
        switch (execOverlay) {
          case 1:
            crossHairs(BLUE);
            break;
          case 2:
            graduations(BLUE);
            break;
          case 3:
            percentGrads(BLUE);
            break;
        }
        frameAvailable = 5;
      } else {
        frameAvailable = 0;
        if (guideFrame.data) {
          free(guideFrame.data);
          guideFrame.data = NULL;
        }
        frameAvailable = 0;
        //guideFrame.data = NULL;
      }
    }
  }
  endoverlay = millis();

    //*********************************************************************************
  // execute demo functions if selected
  if (execDemo) {
    if (execFollower) {
      // call line follower demo routine
      lineFollower();
    } else if (execBlobFollower) {
      // call blob follower routine
      blobFollower();
    } else if (execTargetFollower) {
      // call target follower routine
      targetFollower();
    } else execDemo = 0;
  }
  endloop = millis();
  if (startconv) {
    if (debugSerial) { Serial.printf("Start loop = %d, Conversion = %d Detect = %d, Overlay = %d, Loop = %d  Interval = %d\n", loopTimer, endconv - startconv, enddetect - endconv, endoverlay - enddetect, endloop - loopTimer, convgap); }
  }
  // end of loop routine
}

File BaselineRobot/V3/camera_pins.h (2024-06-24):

// these are the camera pin definitions for different models of camera
// they are selected in the main L0cost Robot code
#if defined(CAMERA_MODEL_WROVER_KIT)
#define PWDN_GPIO_NUM -1
#define RESET_GPIO_NUM -1
#define XCLK_GPIO_NUM 21
#define SIOD_GPIO_NUM 26
#define SIOC_GPIO_NUM 27

#define Y9_GPIO_NUM 35
#define Y8_GPIO_NUM 34
#define Y7_GPIO_NUM 39
#define Y6_GPIO_NUM 36
#define Y5_GPIO_NUM 19
#define Y4_GPIO_NUM 18
#define Y3_GPIO_NUM 5
#define Y2_GPIO_NUM 4
#define VSYNC_GPIO_NUM 25
#define HREF_GPIO_NUM 23
#define PCLK_GPIO_NUM 22

#elif defined(CAMERA_MODEL_ESP_EYE)
#define PWDN_GPIO_NUM -1
#define RESET_GPIO_NUM -1
#define XCLK_GPIO_NUM 4
#define SIOD_GPIO_NUM 18
#define SIOC_GPIO_NUM 23

#define Y9_GPIO_NUM 36
#define Y8_GPIO_NUM 37
#define Y7_GPIO_NUM 38
#define Y6_GPIO_NUM 39
#define Y5_GPIO_NUM 35
#define Y4_GPIO_NUM 14
#define Y3_GPIO_NUM 13
#define Y2_GPIO_NUM 34
#define VSYNC_GPIO_NUM 5
#define HREF_GPIO_NUM 27
#define PCLK_GPIO_NUM 25

#define LED_GPIO_NUM 22

#elif defined(CAMERA_MODEL_M5STACK_PSRAM)
#define PWDN_GPIO_NUM -1
#define RESET_GPIO_NUM 15
#define XCLK_GPIO_NUM 27
#define SIOD_GPIO_NUM 25
#define SIOC_GPIO_NUM 23

#define Y9_GPIO_NUM 19
#define Y8_GPIO_NUM 36
#define Y7_GPIO_NUM 18
#define Y6_GPIO_NUM 39
#define Y5_GPIO_NUM 5
#define Y4_GPIO_NUM 34
#define Y3_GPIO_NUM 35
#define Y2_GPIO_NUM 32
#define VSYNC_GPIO_NUM 22
#define HREF_GPIO_NUM 26
#define PCLK_GPIO_NUM 21

#elif defined(CAMERA_MODEL_M5STACK_V2_PSRAM)
#define PWDN_GPIO_NUM -1
#define RESET_GPIO_NUM 15
#define XCLK_GPIO_NUM 27
#define SIOD_GPIO_NUM 22
#define SIOC_GPIO_NUM 23

#define Y9_GPIO_NUM 19
#define Y8_GPIO_NUM 36
#define Y7_GPIO_NUM 18
#define Y6_GPIO_NUM 39
#define Y5_GPIO_NUM 5
#define Y4_GPIO_NUM 34
#define Y3_GPIO_NUM 35
#define Y2_GPIO_NUM 32
#define VSYNC_GPIO_NUM 25
#define HREF_GPIO_NUM 26
#define PCLK_GPIO_NUM 21

#elif defined(CAMERA_MODEL_M5STACK_WIDE)
#define PWDN_GPIO_NUM -1
#define RESET_GPIO_NUM 15
#define XCLK_GPIO_NUM 27
#define SIOD_GPIO_NUM 22
#define SIOC_GPIO_NUM 23

#define Y9_GPIO_NUM 19
#define Y8_GPIO_NUM 36
#define Y7_GPIO_NUM 18
#define Y6_GPIO_NUM 39
#define Y5_GPIO_NUM 5
#define Y4_GPIO_NUM 34
#define Y3_GPIO_NUM 35
#define Y2_GPIO_NUM 32
#define VSYNC_GPIO_NUM 25
#define HREF_GPIO_NUM 26
#define PCLK_GPIO_NUM 21

#define LED_GPIO_NUM 2

#elif defined(CAMERA_MODEL_M5STACK_ESP32CAM)
#define PWDN_GPIO_NUM -1
#define RESET_GPIO_NUM 15
#define XCLK_GPIO_NUM 27
#define SIOD_GPIO_NUM 25
#define SIOC_GPIO_NUM 23

#define Y9_GPIO_NUM 19
#define Y8_GPIO_NUM 36
#define Y7_GPIO_NUM 18
#define Y6_GPIO_NUM 39
#define Y5_GPIO_NUM 5
#define Y4_GPIO_NUM 34
#define Y3_GPIO_NUM 35
#define Y2_GPIO_NUM 17
#define VSYNC_GPIO_NUM 22
#define HREF_GPIO_NUM 26
#define PCLK_GPIO_NUM 21

#elif defined(CAMERA_MODEL_M5STACK_UNITCAM)
#define PWDN_GPIO_NUM -1
#define RESET_GPIO_NUM 15
#define XCLK_GPIO_NUM 27
#define SIOD_GPIO_NUM 25
#define SIOC_GPIO_NUM 23

#define Y9_GPIO_NUM 19
#define Y8_GPIO_NUM 36
#define Y7_GPIO_NUM 18
#define Y6_GPIO_NUM 39
#define Y5_GPIO_NUM 5
#define Y4_GPIO_NUM 34
#define Y3_GPIO_NUM 35
#define Y2_GPIO_NUM 32
#define VSYNC_GPIO_NUM 22
#define HREF_GPIO_NUM 26
#define PCLK_GPIO_NUM 21

#elif defined(CAMERA_MODEL_AI_THINKER)
#define PWDN_GPIO_NUM 32
#define RESET_GPIO_NUM -1
#define XCLK_GPIO_NUM 0
#define SIOD_GPIO_NUM 26
#define SIOC_GPIO_NUM 27

#define Y9_GPIO_NUM 35
#define Y8_GPIO_NUM 34
#define Y7_GPIO_NUM 39
#define Y6_GPIO_NUM 36
#define Y5_GPIO_NUM 21
#define Y4_GPIO_NUM 19
#define Y3_GPIO_NUM 18
#define Y2_GPIO_NUM 5
#define VSYNC_GPIO_NUM 25
#define HREF_GPIO_NUM 23
#define PCLK_GPIO_NUM 22

#define LED_GPIO_NUM 33

#elif defined(CAMERA_MODEL_TTGO_T_JOURNAL)
#define PWDN_GPIO_NUM 0
#define RESET_GPIO_NUM 15
#define XCLK_GPIO_NUM 27
#define SIOD_GPIO_NUM 25
#define SIOC_GPIO_NUM 23

#define Y9_GPIO_NUM 19
#define Y8_GPIO_NUM 36
#define Y7_GPIO_NUM 18
#define Y6_GPIO_NUM 39
#define Y5_GPIO_NUM 5
#define Y4_GPIO_NUM 34
#define Y3_GPIO_NUM 35
#define Y2_GPIO_NUM 17
#define VSYNC_GPIO_NUM 22
#define HREF_GPIO_NUM 26
#define PCLK_GPIO_NUM 21


#elif defined(CAMERA_MODEL_ESP32_CAM_BOARD)
// The 18 pin header on the board has Y5 and Y3 swapped
#define USE_BOARD_HEADER 0
#define PWDN_GPIO_NUM 32
#define RESET_GPIO_NUM 33
#define XCLK_GPIO_NUM 4
#define SIOD_GPIO_NUM 18
#define SIOC_GPIO_NUM 23

#define Y9_GPIO_NUM 36
#define Y8_GPIO_NUM 19
#define Y7_GPIO_NUM 21
#define Y6_GPIO_NUM 39
#if USE_BOARD_HEADER
#define Y5_GPIO_NUM 13
#else
#define Y5_GPIO_NUM 35
#endif
#define Y4_GPIO_NUM 14
#if USE_BOARD_HEADER
#define Y3_GPIO_NUM 35
#else
#define Y3_GPIO_NUM 13
#endif
#define Y2_GPIO_NUM 34
#define VSYNC_GPIO_NUM 5
#define HREF_GPIO_NUM 27
#define PCLK_GPIO_NUM 25

#elif defined(CAMERA_MODEL_ESP32S3_CAM_LCD)
#define PWDN_GPIO_NUM -1
#define RESET_GPIO_NUM -1
#define XCLK_GPIO_NUM 40
#define SIOD_GPIO_NUM 17
#define SIOC_GPIO_NUM 18
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

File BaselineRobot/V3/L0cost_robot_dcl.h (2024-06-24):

// This header file has been created to separate the extensive number of global variables
// the following are code prototypes ++++++++++++++++++++++++++++
int setup_sdcard(void);
void read_SDcard(void);
void fileParse(char *line, int fileType, int lineNo);
int read_datafile(fs::FS &fs, const char *path, int fileType);
int readHtml(fs::FS &fs, const char *htmlf);

// flagset routines
void flagSet(char execType[20]);
void flagReport(void);

// robothandler routines
int cmdProcessor(char variable[], int source);
int sendHandshake(char commsString[]);
int remoteProcessor(char commsString[], int source);
int localProcessor(char localVariable[], int source);
void initPWM();
int motorControl(char localVariable[], int source);
int motorControl2(char localVariable[], int source);
int shiftLeft(char variable[], int step);
int initServos(void);
int servoControl(char localVariable[]);
int servoControl2(char localVariable[]);
void fileProcessor(int type);
int serialProcessor(int type);
int getValue(char fullCommand[], int offset);
int cmdCmp(char fullCommand[], char testCommand[]);
int cameraControl(char localVariable[]);
int guideControl(char localVariable[]);
void shiftFileName(char *fileName);
void initThreePin(void);
int ps3Processor(char ps3Command[], int source);
int htmlProcessor(char htmlCommand[], int source);
int lockSet(int &lock, int value);
int lockUnSet(int &lock, int value);
int lockTest(int &lock, int value);
void picoPinOn();
void picoPinOff();

// video handling routines
int videoProcessing(void);
int setVideoMode();
int setGuideMode();
long findLineCentre(long colour);
long findLineTop(long colour);
long findLineBottom(long colour);
long findLine(long lineInstances[13], long colour, long startLine, long startCol, long endCol, long threshold, long adjacent, long column, long update);
long findBlob(int colour);
int scanBlob(int pixLine, int pixCol);
int scanTest(long colour);
int setPixel(long location, int colour);
long heatMap(long colour, int background);
long findColours(void);
int crossHairs(long colour);
int graduations(long colour);
int percentGrads(long colour);
long detectColour(long pixel, int colour);
int pixelLuminance(void);
int procGuidance(int type);
int writeMask(int colour);
int calibrate(int type, int colour); 

// PS3 routines
void onConnect();
void notify();

// demo functions
int demoControl(char localVariable[]);
int lineFollower(void);
int blobFollower(void);
int targetFollower(void);

// html routines
static esp_err_t index_handler(httpd_req_t *req);
static esp_err_t stream_handler(httpd_req_t *req);
static esp_err_t cmd_handler(httpd_req_t *req);
static esp_err_t data_handler(httpd_req_t *req);
void startWebServer();

//++++++++++++++++++++++++++++++++++++++++++++++++++++++++++++++++

#define WIFI 1
#define CMDFILE 2
#define CONFIG 3
#define PS3CONFIG 4


#define FLASH_PIN 4
#define LED_BUILTIN 33

// demo function variables
int factorP = 1;    // Proportional PID factor. This is to be interpreted as a 2.2 decimal number
int factorI = 0;    // Integral PID factor. This is to be interpreted as a 2.2 decimal number
int factorD = 0;    // Derivative PID factor. This is to be interpreted as a 2.2 decimal number

// debug variables
int webSwitch = 1;


// execution flags
// these switches are mostly set by configuration or commands and used to direct program execution
int execWiFi = 0;            // use wifi, value indicates 0= no wifi, 1=client or 2=access point
int execPS3 = 0;             // use PS3 input
int execSensor = 0;          // use serial pins for local sensor input
int execSerial = 1;          // configure and pass output to serial port
int execMotor = 0;           // configure motor control output
int execHandshake = 0;       // pins configured for remote controller serial handshake
int execServo = 0;           // configure servo control output, valu indicates either 2 or 4 pins
int execPWM = 0;             // motor control attached
int execPolarity = 0;        // motor polarity, 0 = negative, 1 = positive
int execVideo = 1;           // activate video streaming
int execGuide = 0;           // activate video guidance
int execScript = 1;          // activate script processing
int execLine = 0;            // activate line following video processing
int execLineProcessing = 0;  // type of line processing to carry out 0 = centre, 1 = centre and bottom, 2 = top, centre and bottom
int execBlob = 0;            // activate blob following video processing
int execBlobProcessing = 0;  // activate type of blob processing, 0 = standard
int execOverlay = 0;         // add overlay to guide video display
int execPico = 0;            // activates bidirectional serial protocal with Raspberry Pi Pico
int execMask = 0;            // masks out a portion of the image (all values set to black)
int execCalibrate = 0;       // run calibration routine
int execCamera = 0;           // flag to indicate that camera processing is available

int execDemo = 0;           // set if demo activity selected
int execFollower = 0;       // set if line follower demonstration used
int execBlobFollower = 0;   // set if blob follower demonstration used
int execTargetFollower = 0; // set if blob tracker demonstration used

// demo processing
int demoStatus = 0;         // maintains demo status 0 = no action, 1 = calibrate, 2 = follow


// pico processing section
char sequenceNumber[5] = "    ";  // pico sends a sequence number which must be returned as header to response
int picoPin = 13;                 // hardware handshake pin


// script file processing
char scriptFile[20] = "/startup.txt";       // default script name
int scriptStatus = 0;                      // maintains status of current script execution
int scriptProcess = 0;                      // tracks current script process
char scriptBuf[200];                        // buffer for script processing
File script;                                // file definition for script processing

// timer counters
long loopTimer = 0;     // main timer variable for loop
long ledTimer = 0;
long runTimer = 0;
long scriptTimer = 0;
int errorTimer = 500;   // led flash delay 500ms is for wifi connected ok, 250ms of for camera not working

// timers for motor control
long motorTimer = 0;          // timeout for last motor command
long directTimer = 0;         // timeout for direct control
long defaultTimeOut = 30000;  // default set to 30 seconds
long directTimeOut = 30000;

// flash led timer definitions
#define FLASH_ON_TIME 99999999  // flash LED timer set to 10,000 seconds, could be more but just sets a practical limit
#define FLASH_PEEK_TIME 5000
long flashTimer = FLASH_ON_TIME;
int flashIntensity = 128;  // default PWM value for flash LED when illuminated
const int flashPWMChannel = 7;
int flashState = 0;

// configuration defaults and variables
// These are expected to be loaded from the SDcard but defaults are set here
char *htmlPage;
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

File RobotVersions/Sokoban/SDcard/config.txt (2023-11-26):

// First parameter indicates mode
// BASICSTA mode, serial passthru on, no handshake, Wifi client, web page input, local drive commands processed to drive pins
// BASICAP mode, serial passthru on, no handshake, Wifi Access Point, web page input, local drive commands processed to drive pins
// BASICPS3 mode, serial passthru on, no handshake, PS3 input, local drive commands processed to drive pins
// BASICSTA+ mode, serial passthru on, no handshake, Wifi client, web page input, local drive commands processed to drive pins, positive drive
// BASICAP+ mode, serial passthru on, no handshake, Wifi Access Point, web page input, local drive commands processed to drive pins, positive drive
// BASICPS3+ mode, serial passthru on, no handshake, PS3 input, local drive commands processed to drive pins, positive drive
// SOKOBANSTA mode, serial passthru on, no handshake, Wifi client, web page input, local drive commands sent to matrix decode L293
// SOKOBANAP mode, serial passthru on, no handshake, Wifi Access Point, web page input, local drive commands sent to matrix decode L293
// SOKOBANPS3 mode, serial passthru on, no handshake, PS3 input, local drive commands sent to matrix decode L293
// REMOTESTA mode, serial passthru on, handshake on, Wifi client, web page input
// REMOTEAP mode, serial passthru on, handshake on, Wifi Access Point, web page input
// REMOTEPS3 mode, serial passthru on, handshake on, PS3 controller input
// SERVOSTA mode, serial passthru on, no handshake, Wifi client, web page input, servo commands processed to 2 pins
// SERVOAP mode, serial passthru on, no handshake, Wifi Access Point, web page input, servo commands processed to 2 pins
// SERVOPS3 mode, serial passthru on, no handshake, PS3 controller input, servo commands processed to 2 pins
SOKOBANSTA
//
// second parameter is the hostname, it must be a valid network name
SOKOBANBOT
//
// third parameter is the filename of the file containing the wifi or PS3 parameters
WiFi.txt
//
// fourth parameter is the filename of the startup script, typically holds default parameter settings
// the file will be ignored if it doesn't exist but has to be present
Startup.txt
//
// fifth parameter is the filename of the main script which contains the list of commands to be initially executed by the controller
Main.txt
